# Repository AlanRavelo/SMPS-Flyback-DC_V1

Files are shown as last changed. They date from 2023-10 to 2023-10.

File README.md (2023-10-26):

## SMPS (Switched-Mode Power Supply)

Fuente_5V_4 8A

## Referencias
* [PI Expert Online](https://www.power.com)
* [DESIGN CONSIDERATIONS FOR FLYBACK TRANSFORMER](https://www.we-online.com/files/pdf1/design-considerations-for-flyback-transformer.pdf)
* [Würth Elektronik](https://www.we-online.com/en/components/products)
* [KiCad.org](https://www.kicad.org/)
* [FreeCad](https://www.freecad.org/)

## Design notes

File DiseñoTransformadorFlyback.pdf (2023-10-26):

# ▼Electrical Diagram

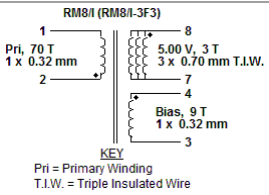
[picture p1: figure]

# ▼Mechanical Diagram

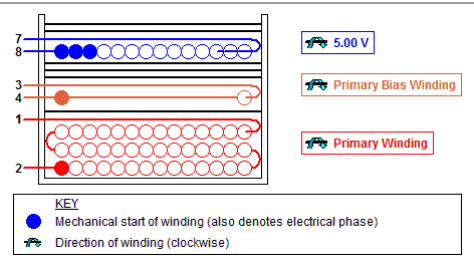
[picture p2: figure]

# ▼Winding Instruction

Primary Winding

Start on pin(s) 2 and wind 70 turns (x 1 filar) of item [5]. in 3 layer(s) from left to right. Winding direction is clockwise. At the end of 1st layer, continue to wind the next layer from right to left. At the end of 2nd layer, continue to wind the next layer from left to right. On

the final layer, spread the winding evenly across entire bobbin. Finish this winding on pin(s) 1.

Add 1 layer of tape, item [3], for insulation.

Primary Bias Winding

Start on pin(s) 4 and wind 9 turns (x 1 filar) of item [5]. Winding direction is clockwise. Spread the winding evenly across entire bobbin. Finish this winding on pin(s) 3.

Add 3 layers of tape, item [3], for insulation.

Secondary Winding

Start on pin(s) 8 and wind 3 turns (x 3 filar) of item [6]. Spread the winding evenly across entire bobbin. Winding direction is clockwise. Finish this winding on pin(s) 7.

Add 2 layers of tape, item [3], for insulation.

Core Assembly

Assemble and secure core halves. Item [1].

Varnish

Dip varnish uniformly in item [4]. Do not vacuum impregnate.

# ▼Comments

1. For non margin wound transformers use triple insulated wire for all secondary windings.

# ▼Materials

Item | Description
[1] Core: RM8/I (RM8/I-3F3), 3F3, gapped for ALG of 270 nH/T²
[2] Bobbin: Generic, 6 pri. + 6 sec.
[3] Barrier Tape: Polyester film [1 mil (25 µm) base thickness], 8.60 mm wide
[4] Varnish
[5] Magnet Wire: 0.32 mm, Solderable Double Coated
[6] Triple Insulated Wire: 0.7 mm

# ▼Electrical Test Specifications

Parameter | Condition | Spec
Electrical Strength, VAC | 60 Hz 1 second, from pins 1,2,3,4 to pins 7,8. | 3900
Nominal Primary Inductance, µH | Measured at 1 V pk-pk, typical switching frequency, between pin 1 to pin 2, with all other Windings open. | 1437
Tolerance, ±% | Tolerance of Primary Inductance | 10.0
Maximum Primary Leakage, µH | Measured between Pin 1 to Pin 2, with all other Windings shorted. | 18.9

Although the design of the software considered safety guidelines, it is the user's responsibility to ensure that the user's power supply design meets all applicable safety requirements of user's product.

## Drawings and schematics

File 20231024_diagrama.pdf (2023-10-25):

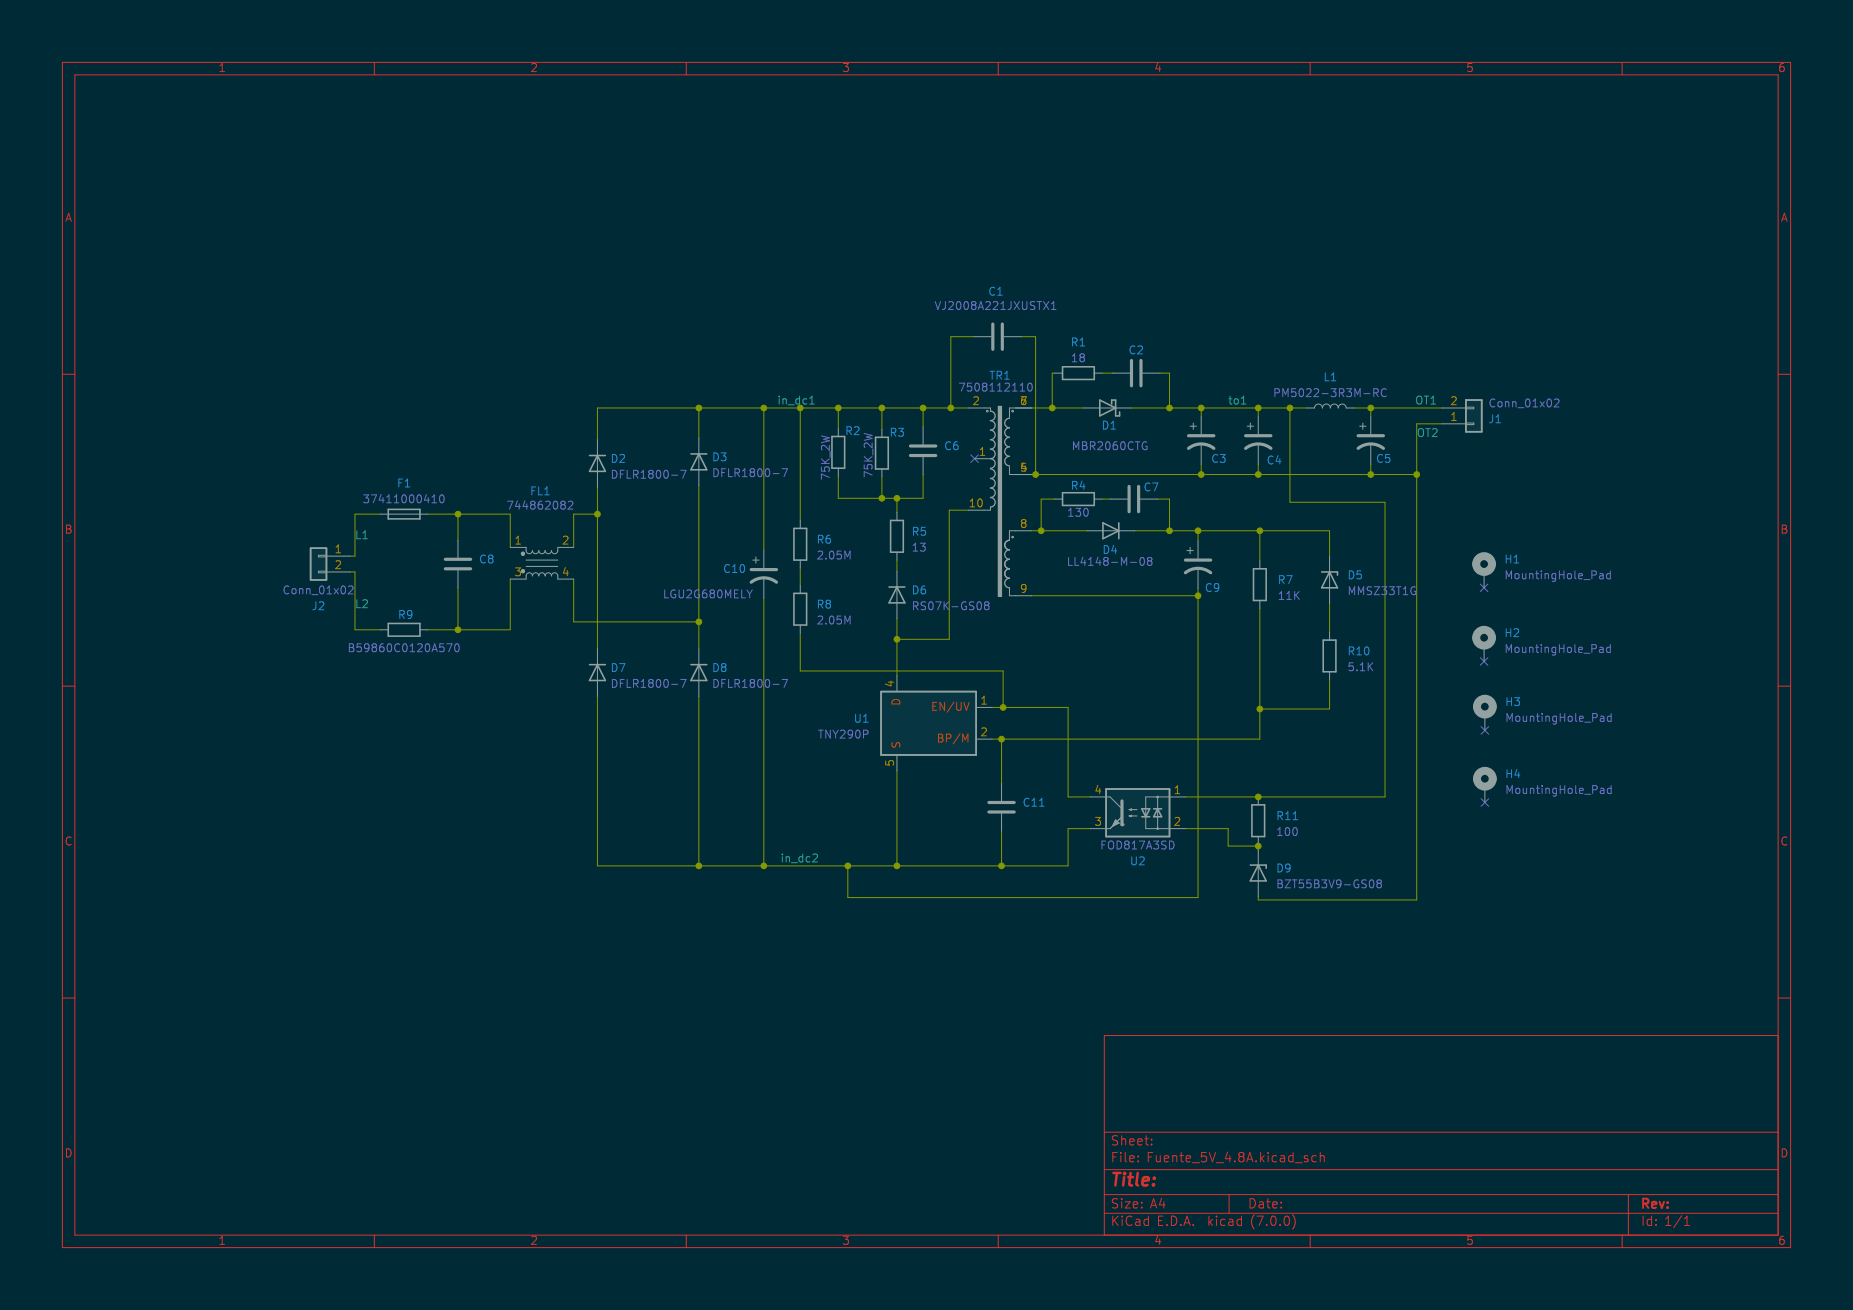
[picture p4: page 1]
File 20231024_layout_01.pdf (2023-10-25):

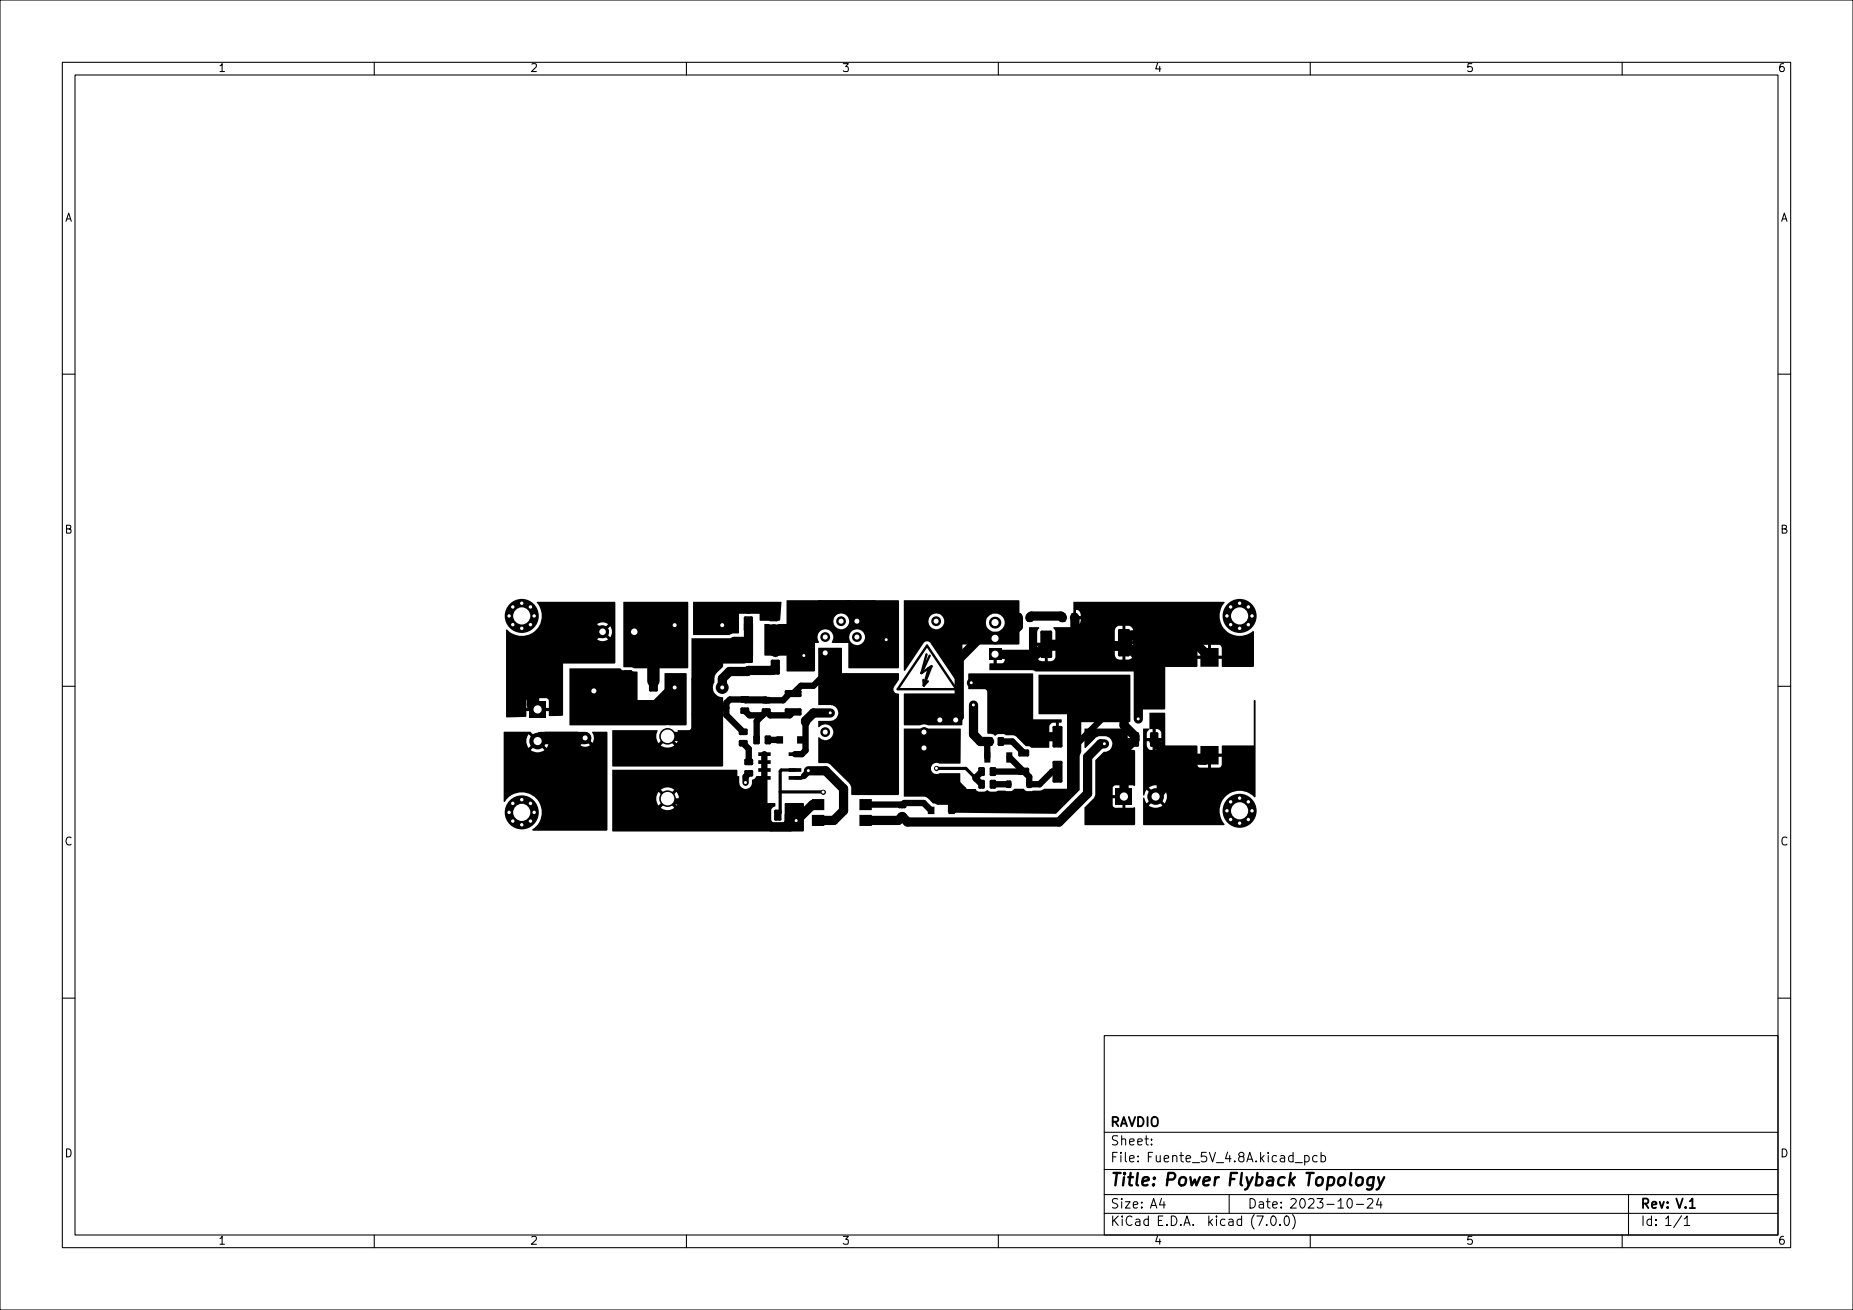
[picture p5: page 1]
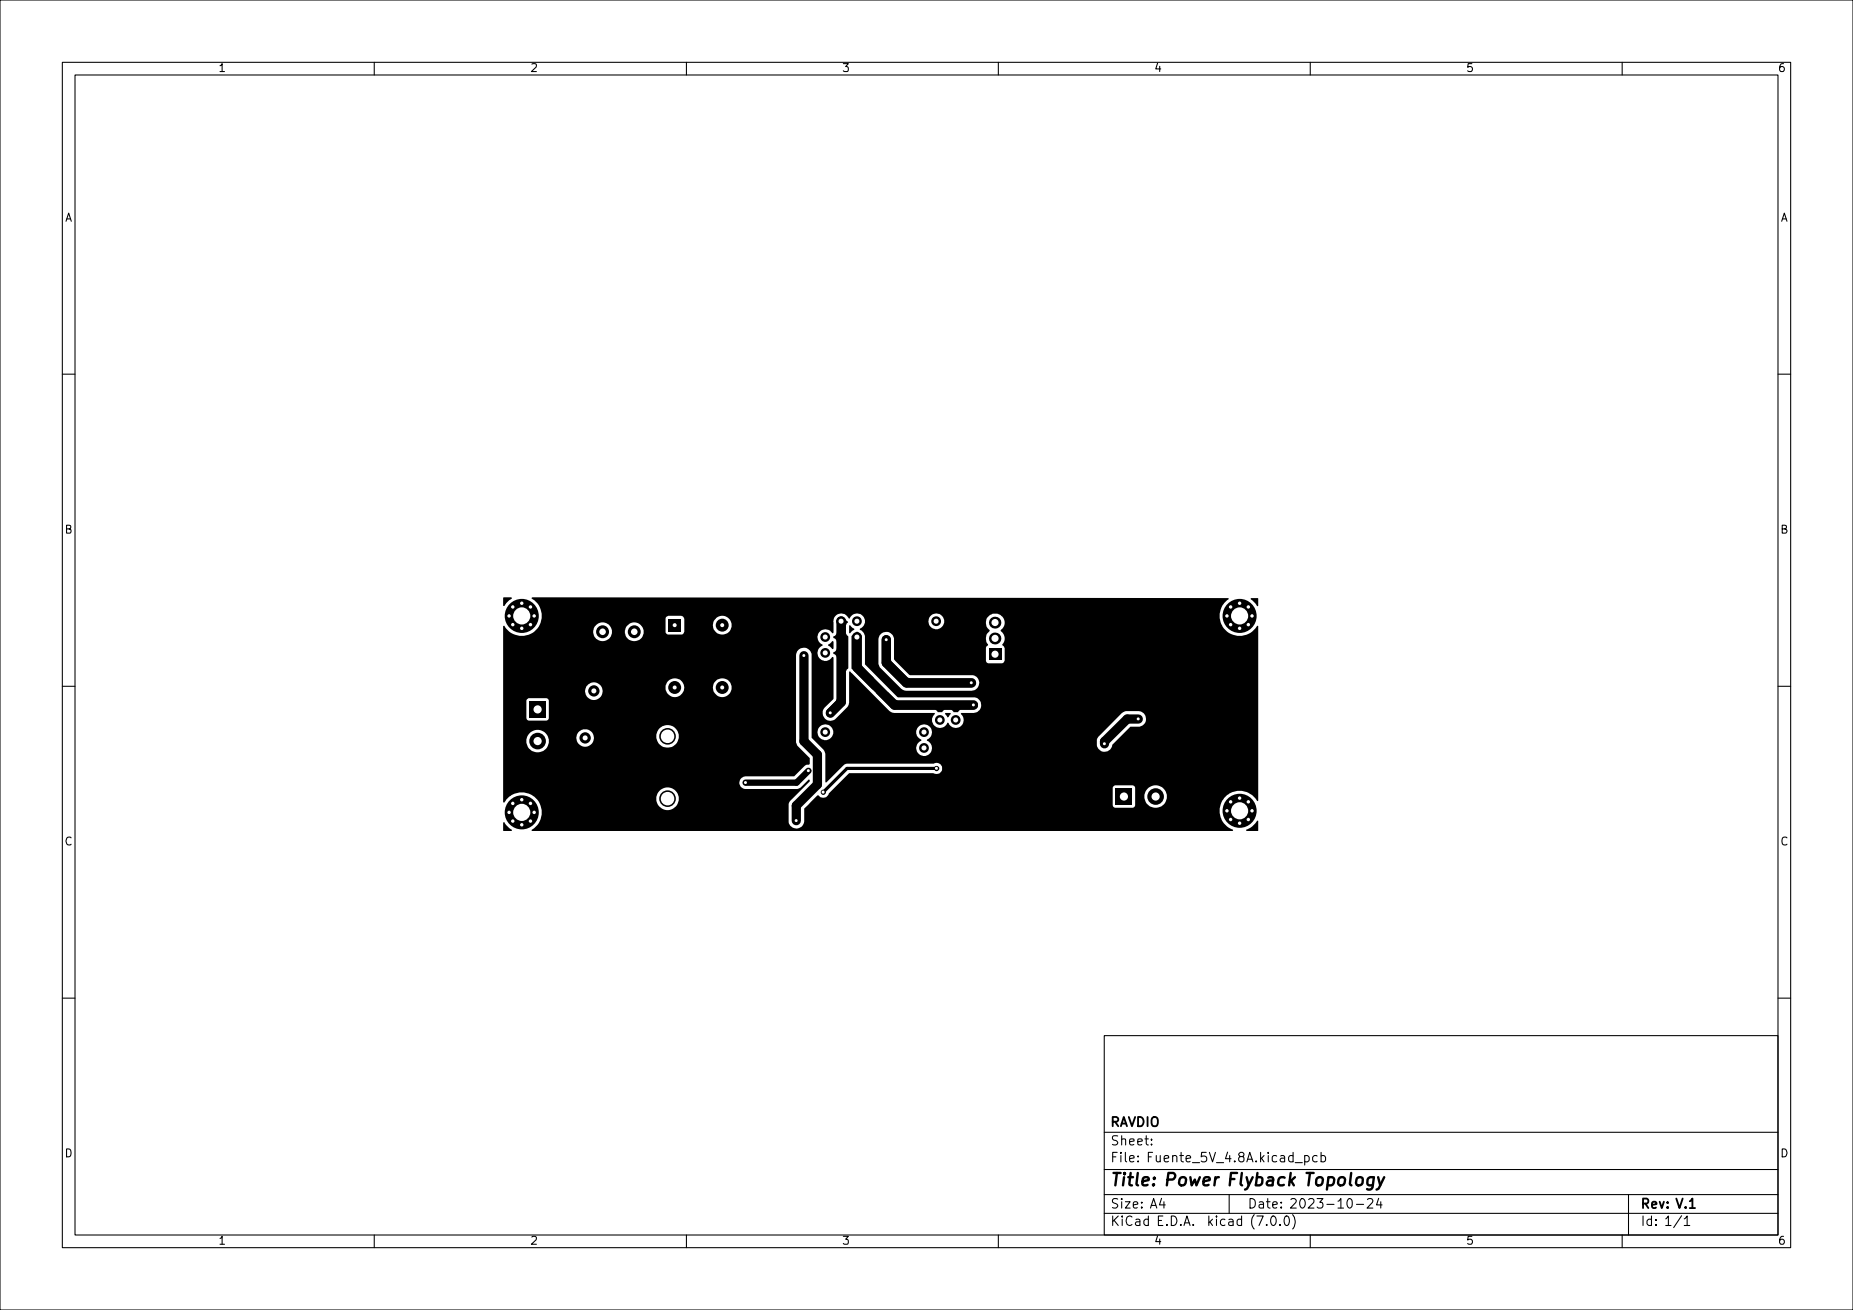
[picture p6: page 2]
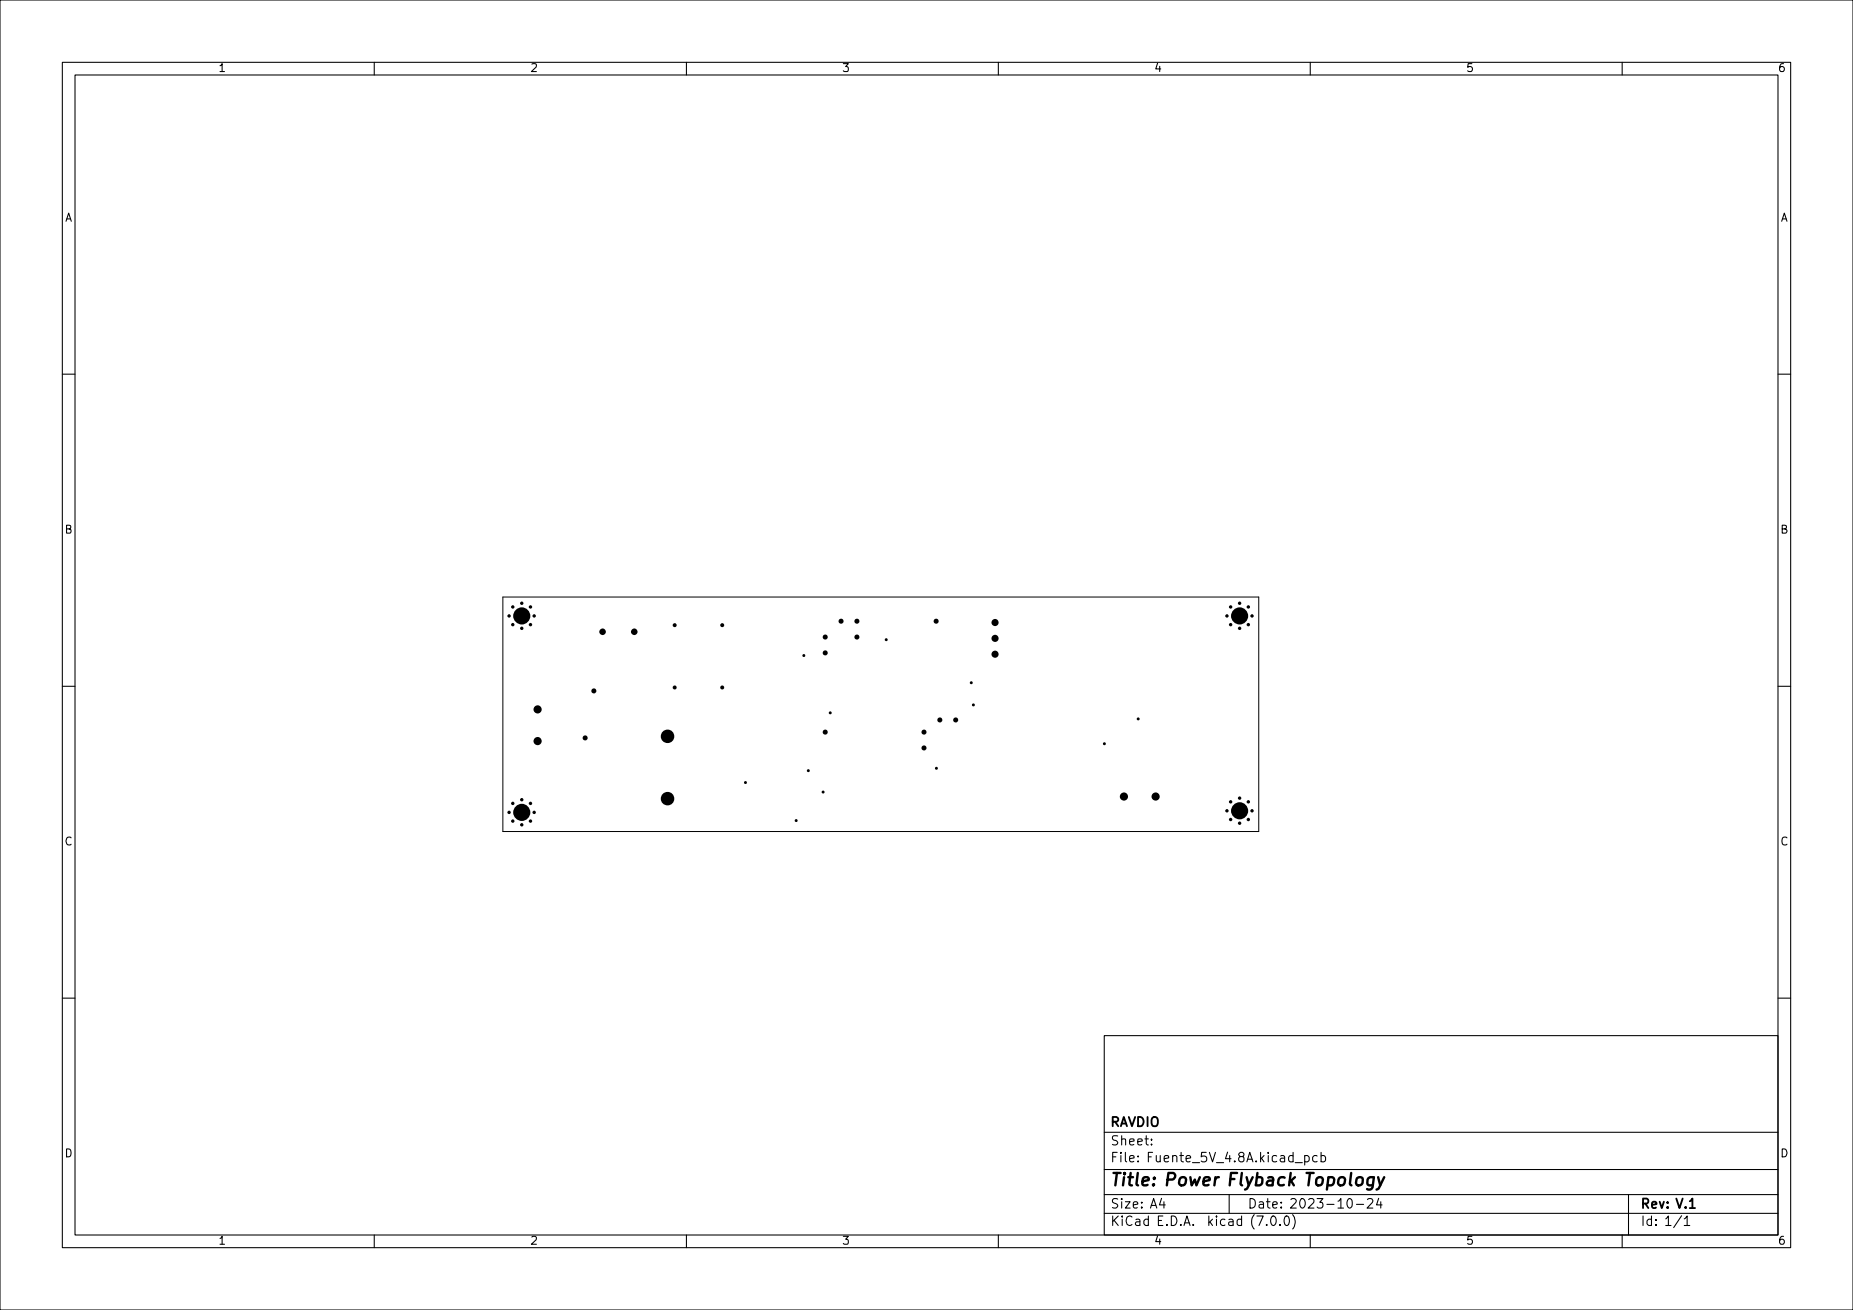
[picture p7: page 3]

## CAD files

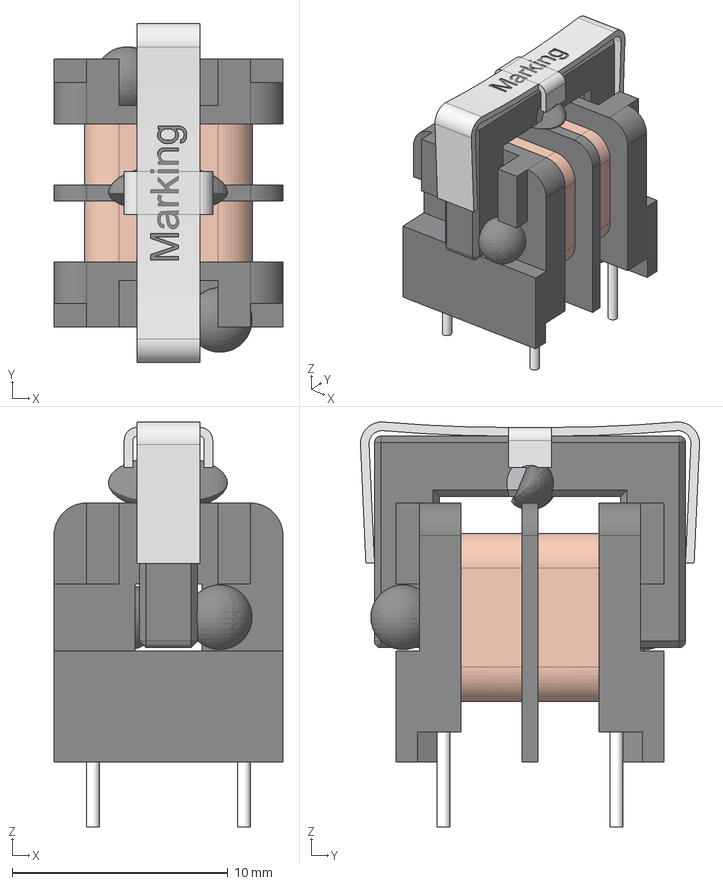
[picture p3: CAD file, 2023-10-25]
WE-TFC_Typ_UT.stp
10.6 x 15.7 x 18.8 mm
bobbin_UU-9.8
core_UU-9.8 x 2
clip_UU-9.8
Glue 3
Glue 2
Glue 1
